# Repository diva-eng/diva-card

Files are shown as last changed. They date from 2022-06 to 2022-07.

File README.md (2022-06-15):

# Diva Card

Raspberry RP2040 based development board/card with builtin LED matrix

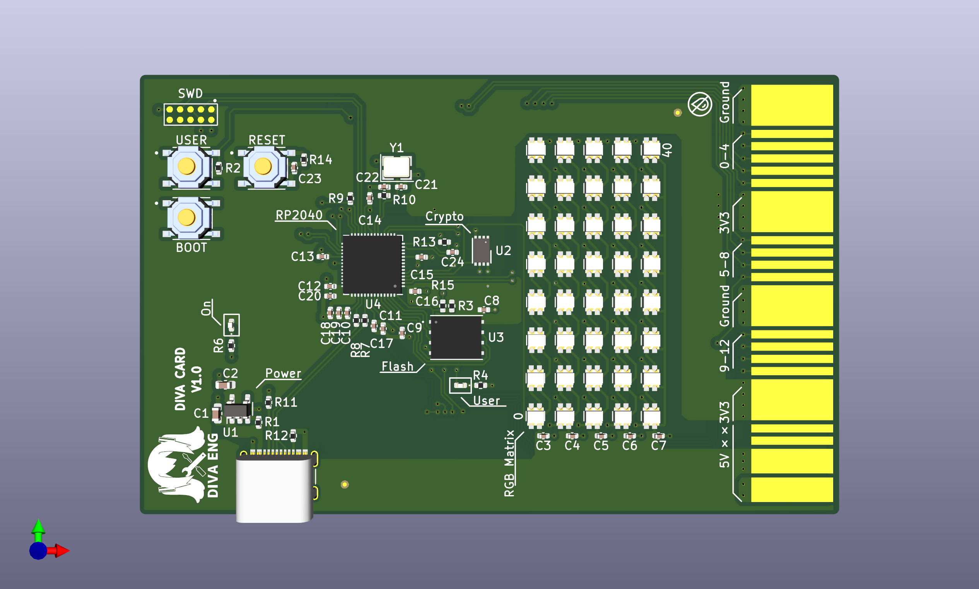
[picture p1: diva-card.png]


## Specs
* RP2040 Dual ARM Cortex-M0+ @ 133MHz
* Microchip ATECC608A crypto processor
* 8*5 WS2812C-2020 RGB LED matrix
* USB-C connector at USB 2.0 speed
* 1 user Button
* 1 user LED
* 13 user IO
* SWD tag connector
* Edge connector for IO/Power

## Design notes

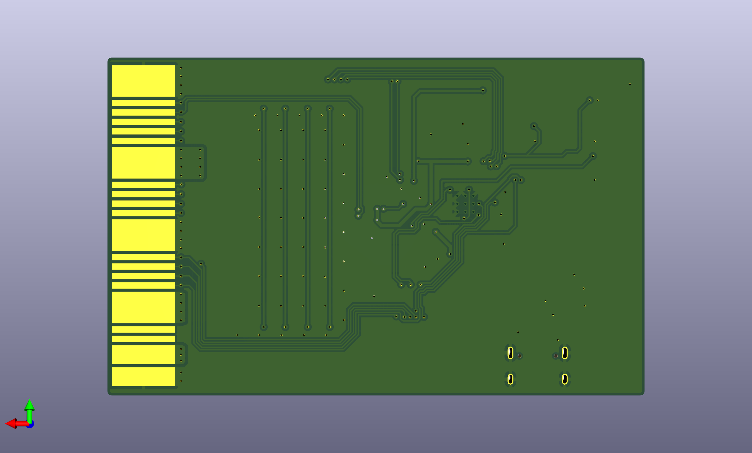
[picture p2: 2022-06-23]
diva-card-back.png

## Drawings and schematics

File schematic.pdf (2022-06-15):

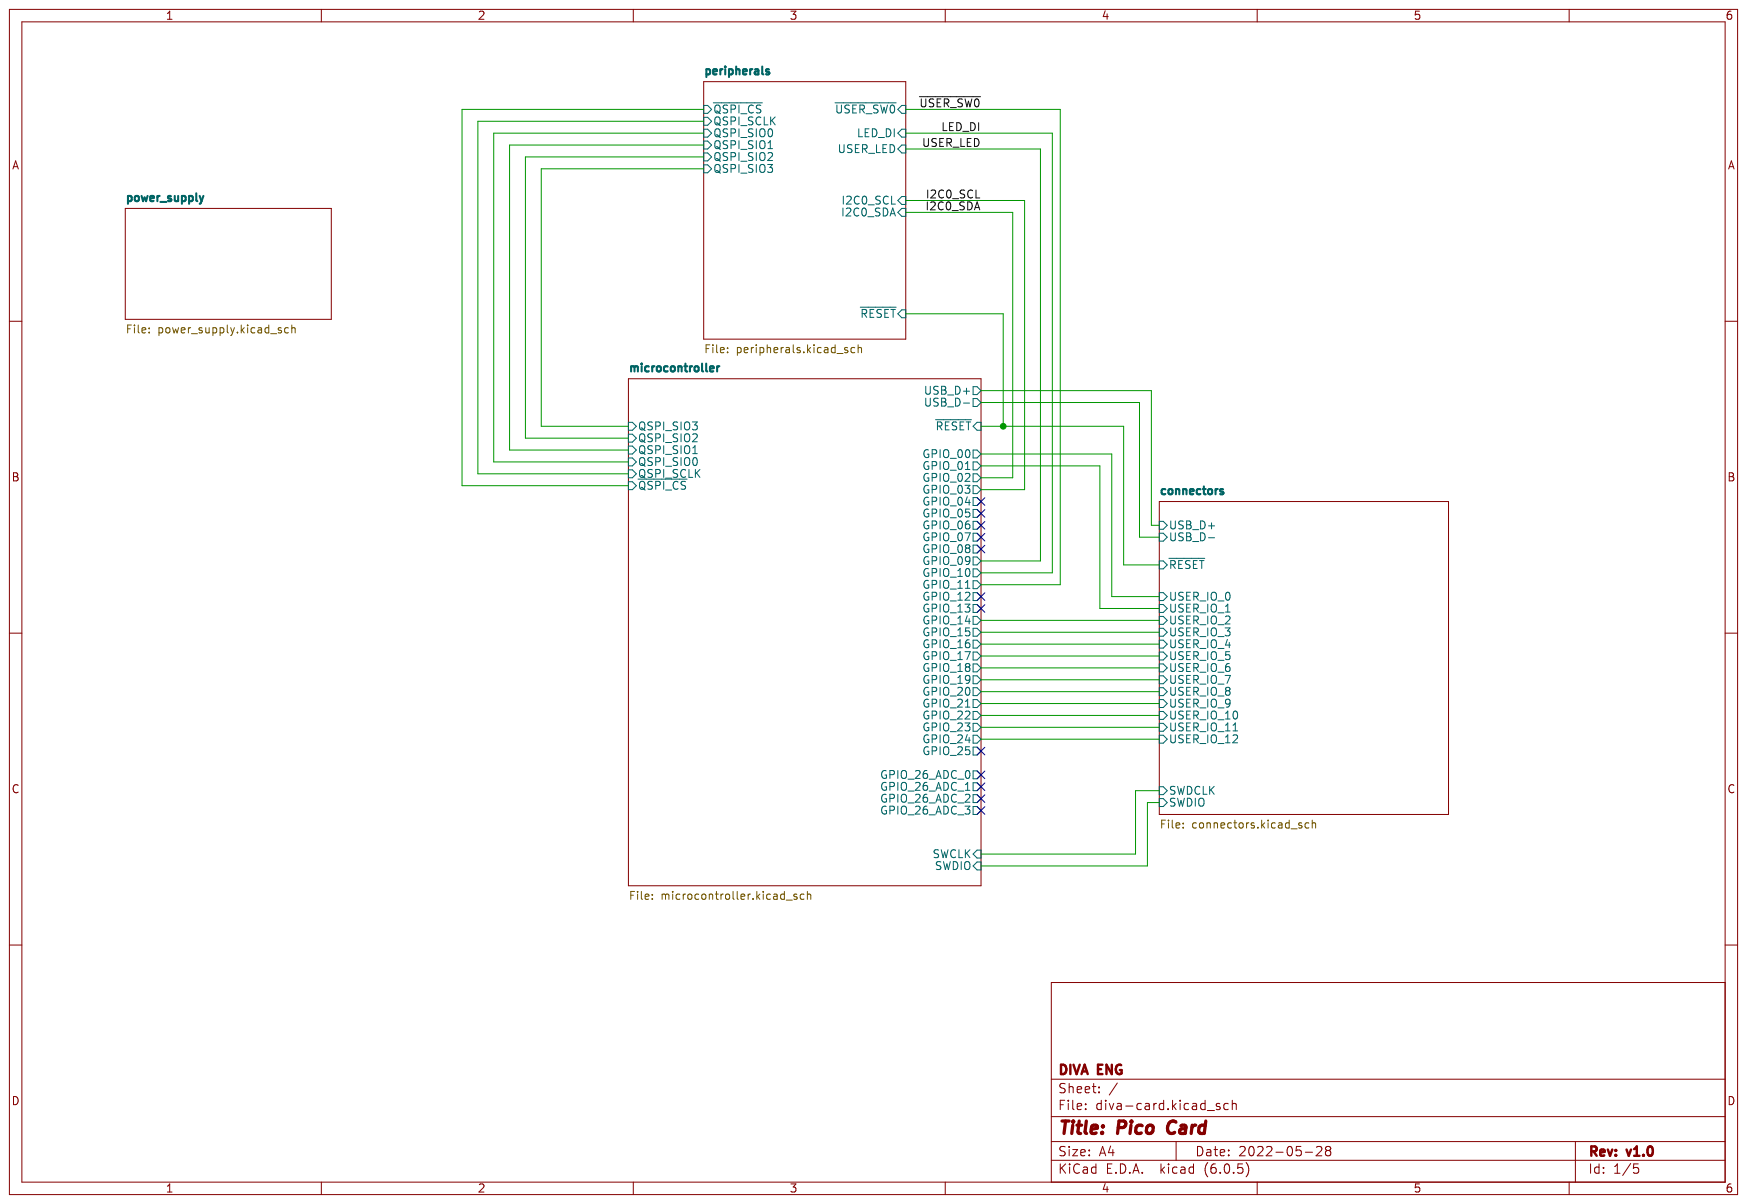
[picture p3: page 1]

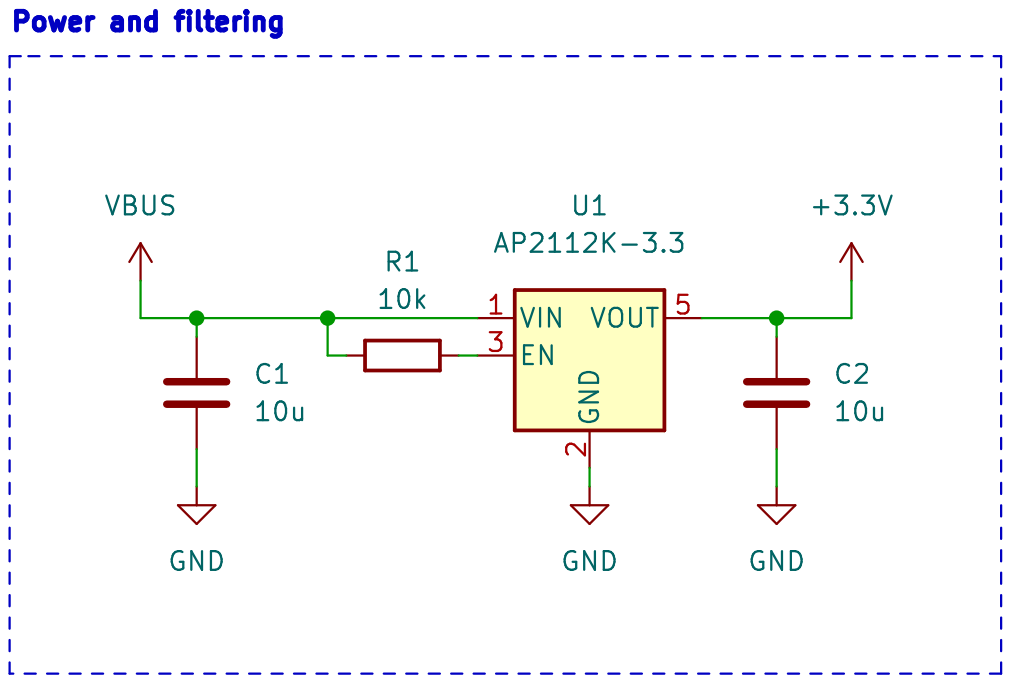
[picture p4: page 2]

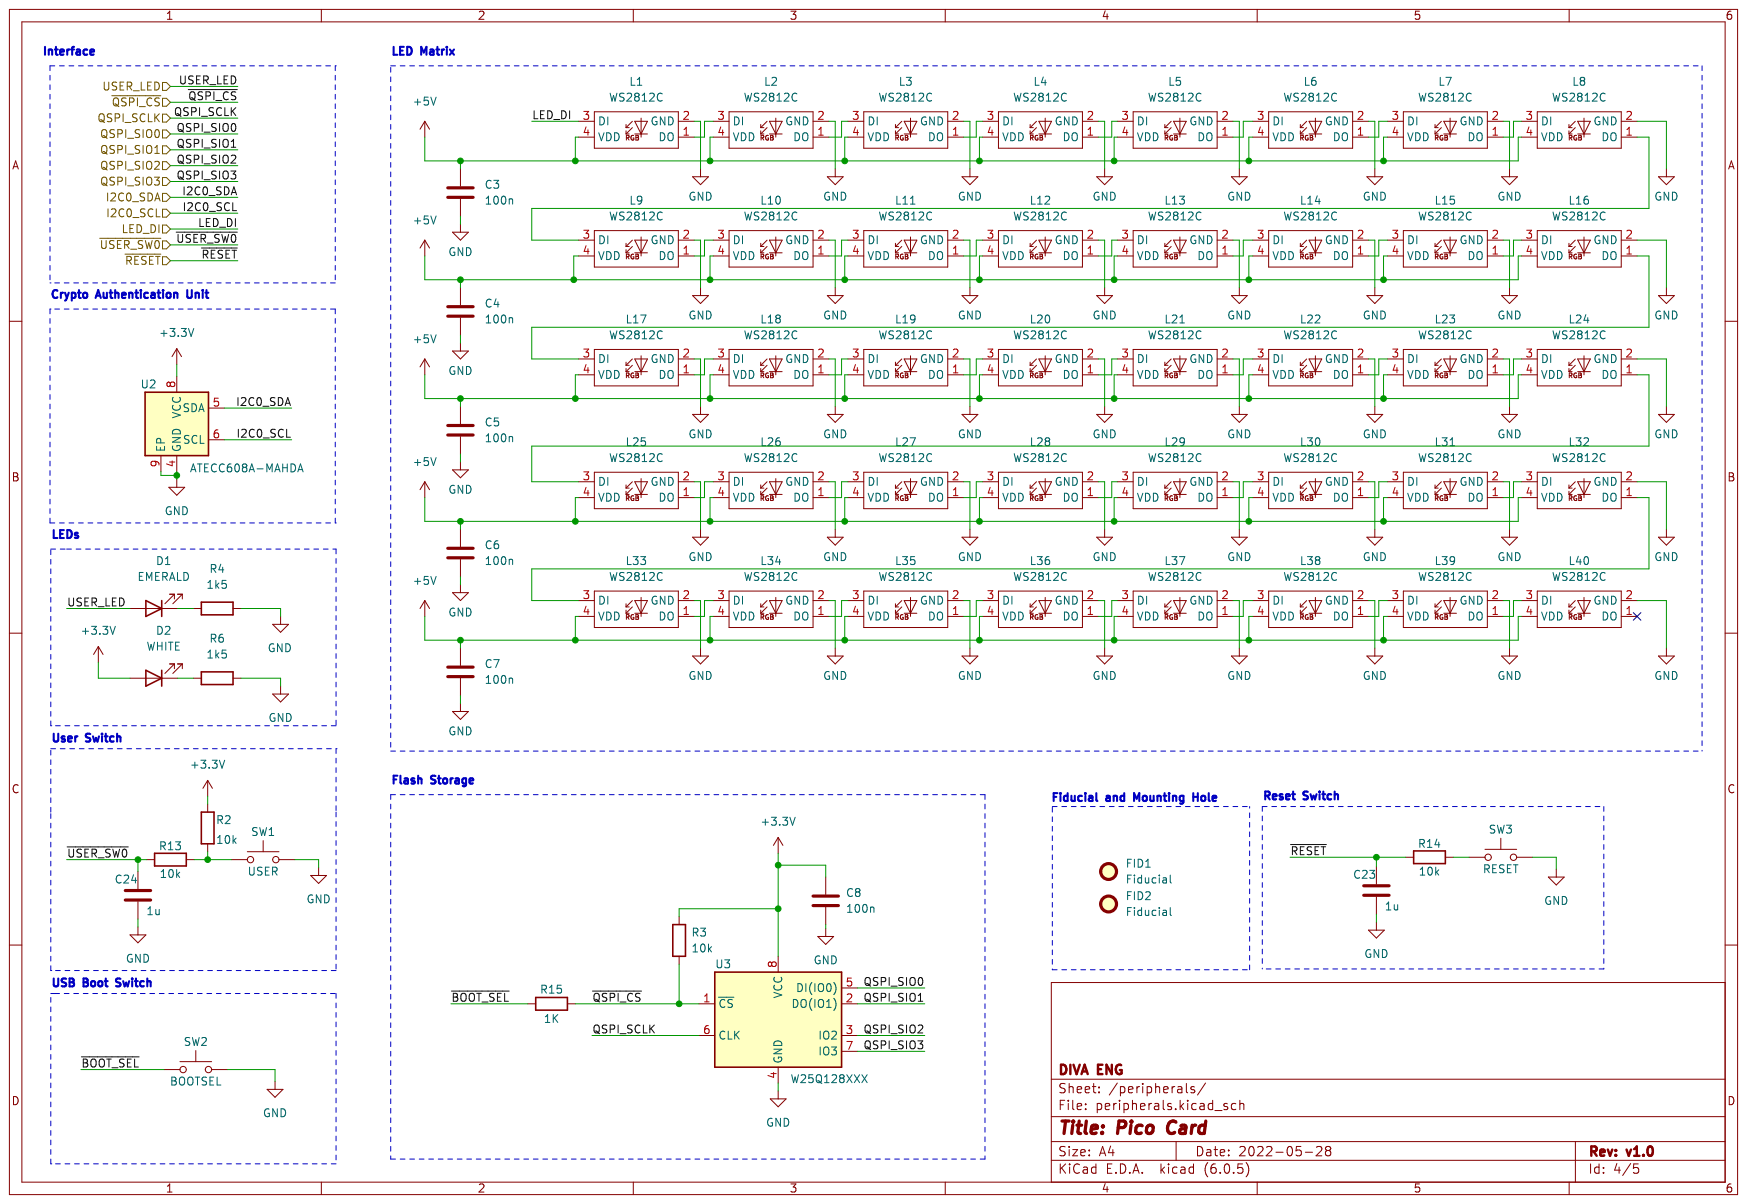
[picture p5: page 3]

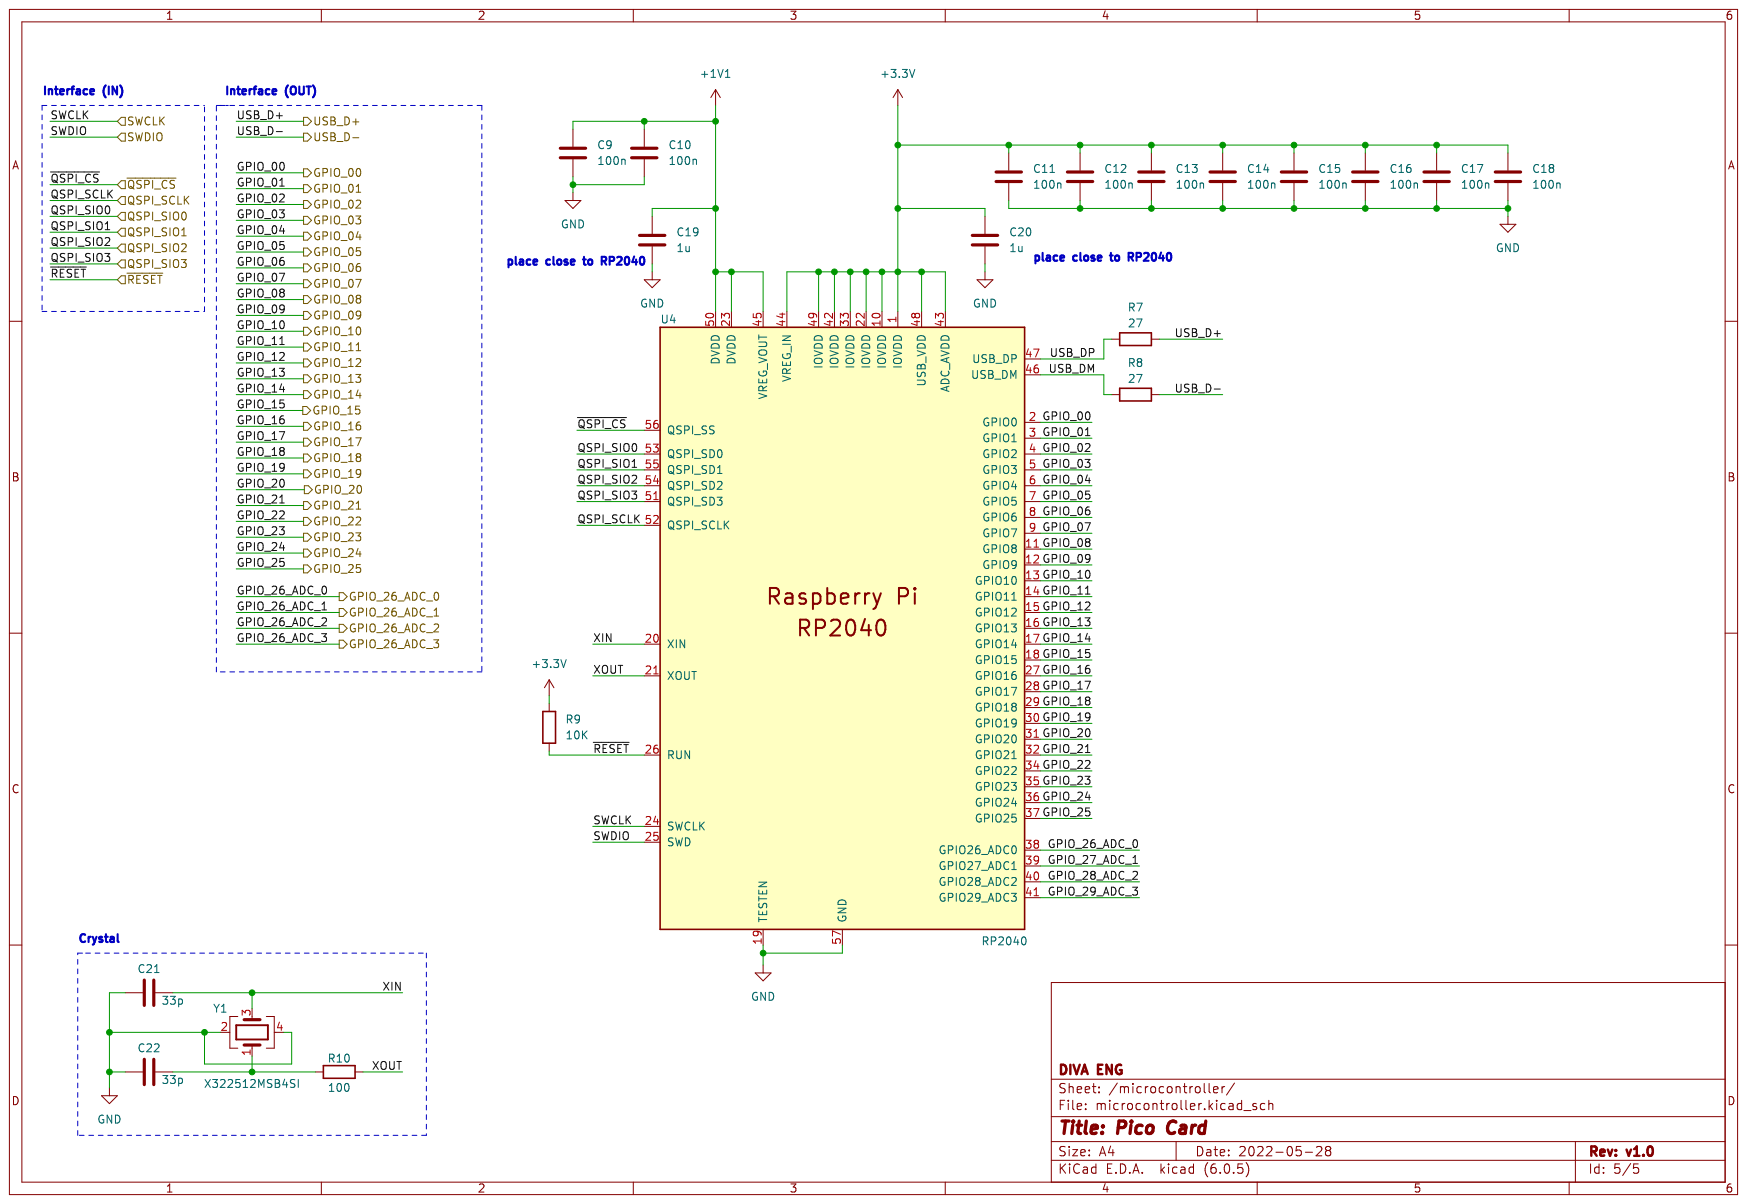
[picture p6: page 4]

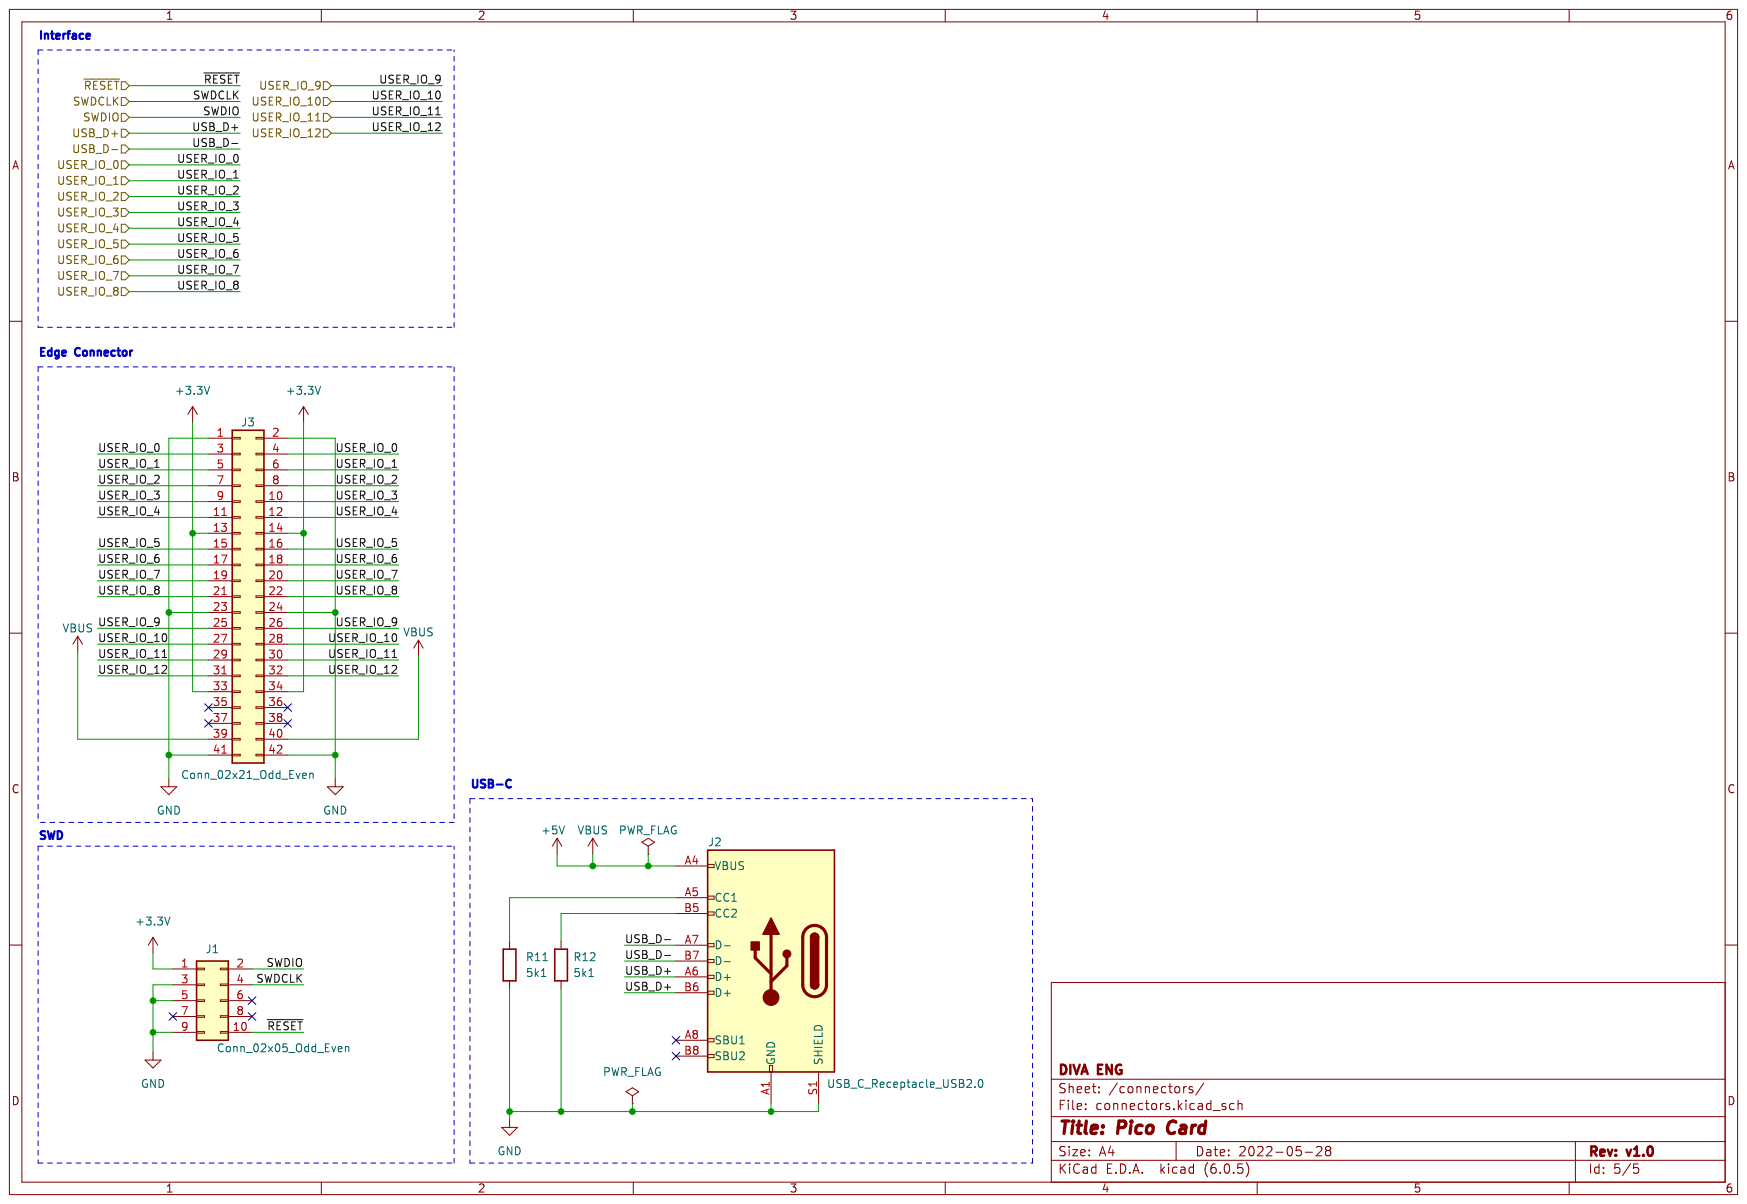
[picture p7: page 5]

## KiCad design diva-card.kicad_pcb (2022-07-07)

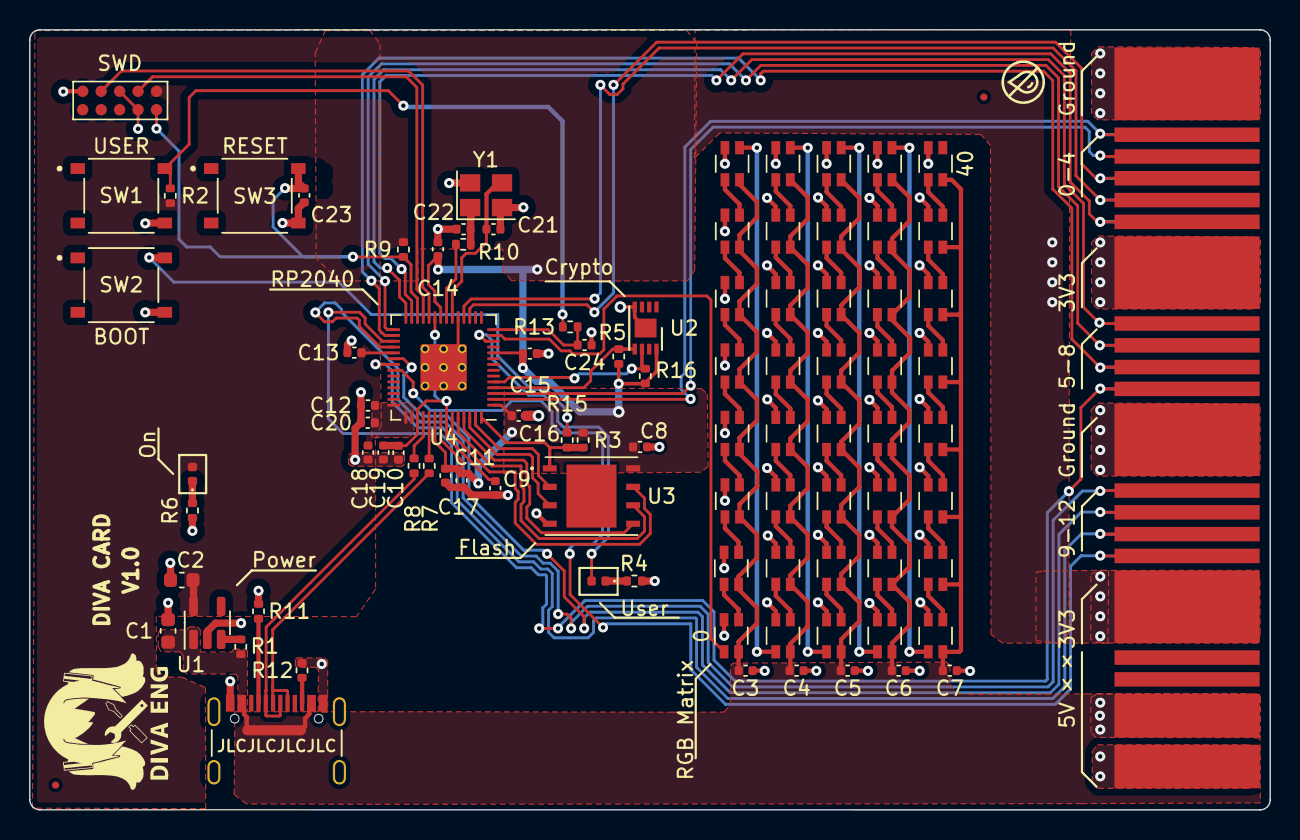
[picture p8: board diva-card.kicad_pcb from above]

Board: 2 copper layers, 85.4 x 53.7 mm, 94 parts (0 on the bottom side), 84 nets.

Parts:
C1, C2: 10u; C_0603_1608Metric
C3, C4, C5, C6, C7, C8, C9, C10, C11, C12, C13, C14, C15, C16, C17, C18: 100n; C_0402_1005Metric
C19, C20, C23, C24: 1u; C_0402_1005Metric
C21, C22: 33p; C_0402_1005Metric
D1: EMERALD; LED_0402_1005Metric
D2: WHITE; LED_0402_1005Metric
FID1, FID2: Fiducial; Fiducial_0.5mm_Mask1mm
J1: Conn_02x05_Odd_Even; Tag-Connect_TC2050-IDC-NL_2x05_P1.27mm_Vertical
J2: USB_C_Receptacle_USB2.0; USB_C_Receptacle_Palconn_UTC16-G
J3: Conn_02x21_Odd_Even; PICO_CARD_EDGE_21
L1, L2, L3, L4, L5, L6, L7, L8, L9, L10, L11, L12, L13, L14, L15, L16, L17, L18, L19, L20, L21, L22, L23, L24, L25, L26, L27, L28, L29, L30, L31, L32, L33, L34, L35, L36, L37, L38, L39, L40: WS2812C; WS2812C-2020
R1, R2, R3, R13: 10k; R_0402_1005Metric
R4, R6: 1k5; R_0402_1005Metric
R5, R16: 4.7k; R_0402_1005Metric
R7, R8: 27; R_0402_1005Metric
R9: 10K; R_0402_1005Metric
R10: 100; R_0402_1005Metric
R11, R12: 5k1; R_0402_1005Metric
R15: 1K; R_0402_1005Metric
SW1: USER; SW_TS-1187A-B-A-B
SW2: BOOTSEL; SW_TS-1187A-B-A-B
SW3: RESET; SW_TS-1187A-B-A-B
U1: AP2112K-3.3; SOT-23-5
U2: ATECC608A-MAHDA; DFN-8-1EP_3x2mm_P0.5mm_EP1.3x1.5mm
U3: W25Q128XXX; W25Q128JVPIQ TR
U4: RP2040; RP2040-QFN-56
Y1: X322512MSB4SI; Crystal_SMD_3225-4Pin_3.2x2.5mm

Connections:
+1V1: C9.1, C10.1, C19.1, U4.23 (DVDD), U4.45 (VREG_VOUT), U4.50 (DVDD)
+3V3: C2.1, C8.1, C11.1, C12.1, C13.1, C14.1, C15.1, C16.1, C17.1, C18.1, C20.1, D2.2 (A), J1.1, J3.13, J3.14, J3.33, J3.34, R2.1, R3.1, R5.1, R9.1, R16.1, U1.5 (VOUT), U2.8 (VCC), U3.8 (VCC), U4.1 (IOVDD), U4.10 (IOVDD), U4.22 (IOVDD), U4.33 (IOVDD), U4.42 (IOVDD), U4.43 (ADC_AVDD), U4.44 (VREG_IN), U4.48 (USB_VDD), U4.49 (IOVDD)
+5V: C1.1, C3.1, C4.1, C5.1, C6.1, C7.1, J2.A4 (VBUS), J2.A9 (VBUS), J2.B4 (VBUS), J2.B9 (VBUS), J3.39, J3.40, L1.4 (VDD), L2.4 (VDD), L3.4 (VDD), L4.4 (VDD), L5.4 (VDD), L6.4 (VDD), L7.4 (VDD), L8.4 (VDD), L9.4 (VDD), L10.4 (VDD), L11.4 (VDD), L12.4 (VDD), L13.4 (VDD), L14.4 (VDD), L15.4 (VDD), L16.4 (VDD), L17.4 (VDD), L18.4 (VDD), L19.4 (VDD), L20.4 (VDD), L21.4 (VDD), L22.4 (VDD), L23.4 (VDD), L24.4 (VDD), L25.4 (VDD), L26.4 (VDD), L27.4 (VDD), L28.4 (VDD), L29.4 (VDD), L30.4 (VDD), L31.4 (VDD), L32.4 (VDD), L33.4 (VDD), L34.4 (VDD), L35.4 (VDD), L36.4 (VDD), L37.4 (VDD), L38.4 (VDD), L39.4 (VDD), L40.4 (VDD), R1.1, U1.1 (VIN)
/I2C0_SCL: R16.2, U2.6 (SCL), U4.5 (GPIO3)
/I2C0_SDA: R5.2, U2.5 (SDA), U4.4 (GPIO2)
/LED_DI: L1.3 (DI), U4.13 (GPIO10)
/USER_LED: D1.2 (A), U4.12 (GPIO9)
/connectors/SWDCLK: J1.4, U4.24 (SWCLK)
/connectors/SWDIO: J1.2, U4.25 (SWD)
/connectors/USB_D+: J2.A6 (D+), J2.B6 (D+), R7.2
/connectors/USB_D-: J2.A7 (D-), J2.B7 (D-), R8.2
/connectors/USER_IO_0: J3.3, J3.4, U4.2 (GPIO0)
/connectors/USER_IO_1: J3.5, J3.6, U4.3 (GPIO1)
/connectors/USER_IO_2: J3.7, J3.8, U4.17 (GPIO14)
/connectors/USER_IO_3: J3.9, J3.10, U4.18 (GPIO15)
/connectors/USER_IO_4: J3.11, J3.12, U4.27 (GPIO16)
/connectors/USER_IO_5: J3.15, J3.16, U4.28 (GPIO17)
/connectors/USER_IO_6: J3.17, J3.18, U4.29 (GPIO18)
/connectors/USER_IO_7: J3.19, J3.20, U4.30 (GPIO19)
/connectors/USER_IO_8: J3.21, J3.22, U4.31 (GPIO20)
/connectors/USER_IO_9: J3.25, J3.26, U4.32 (GPIO21)
/connectors/USER_IO_10: J3.27, J3.28, U4.34 (GPIO22)
/connectors/USER_IO_11: J3.29, J3.30, U4.35 (GPIO23)
/connectors/USER_IO_12: J3.31, J3.32, U4.36 (GPIO24)
/connectors/~RESET: C23.1, J1.10, R9.2, SW3.1, U4.26 (RUN)
/microcontroller/QSPI_SCLK: U3.6 (CLK), U4.52 (QSPI_SCLK)
/microcontroller/QSPI_SIO0: U3.5 (DI(IO0)), U4.53 (QSPI_SD0)
/microcontroller/QSPI_SIO1: U3.2 (DO(IO1)), U4.55 (QSPI_SD1)
/microcontroller/QSPI_SIO2: U3.3 (IO2), U4.54 (QSPI_SD2)
/microcontroller/QSPI_SIO3: U3.7 (IO3), U4.51 (QSPI_SD3)
/microcontroller/USB_DM: R8.1, U4.46 (USB_DM)
/microcontroller/USB_DP: R7.1, U4.47 (USB_DP)
/microcontroller/XIN: C21.2, U4.20 (XIN), Y1.3
/microcontroller/XOUT: R10.2, U4.21 (XOUT)
/microcontroller/~QSPI_CS: R3.2, R15.2, U3.1 (~CS), U4.56 (QSPI_SS)
/peripherals/~BOOT_SEL: R15.1, SW2.1
/~USER_SW0: C24.1, R13.1, U4.14 (GPIO11)
GND: C1.2, C2.2, C3.2, C4.2, C5.2, C6.2, C7.2, C8.2, C9.2, C10.2, C11.2, C12.2, C13.2, C14.2, C15.2, C16.2, C17.2, C18.2, C19.2, C20.2, C21.1, C22.1, C23.2, C24.2, J1.3, J1.5, J1.9, J2.A1 (GND), J2.A12 (GND), J2.B1 (GND), J2.B12 (GND), J2.S1 (SHIELD), J3.1, J3.2, J3.23, J3.24, J3.41, J3.42, L1.2 (GND), L2.2 (GND), L3.2 (GND), L4.2 (GND), L5.2 (GND), L6.2 (GND), L7.2 (GND), L8.2 (GND), L9.2 (GND), L10.2 (GND), L11.2 (GND), L12.2 (GND), L13.2 (GND), L14.2 (GND), L15.2 (GND), L16.2 (GND), L17.2 (GND), L18.2 (GND), L19.2 (GND), L20.2 (GND), L21.2 (GND), L22.2 (GND), L23.2 (GND), L24.2 (GND), L25.2 (GND), L26.2 (GND), L27.2 (GND), L28.2 (GND), L29.2 (GND), L30.2 (GND), L31.2 (GND), L32.2 (GND), L33.2 (GND), L34.2 (GND), L35.2 (GND), L36.2 (GND), L37.2 (GND), L38.2 (GND), L39.2 (GND), L40.2 (GND), R4.2, R6.2, R11.2, R12.2, SW1.2, SW2.2, SW3.2, U1.2 (GND), U2.4 (GND), U2.9 (EP), U3.4 (GND), U4.19 (TESTEN), U4.57 (GND), Y1.2, Y1.4
unnamed: C22.2, R10.1, Y1.1
unnamed: D1.1 (K), R4.1
unnamed: D2.1 (K), R6.1
unnamed: J2.A5 (CC1), R11.1
unnamed: J2.B5 (CC2), R12.1
unnamed: L1.1 (DO), L2.3 (DI)
unnamed: L2.1 (DO), L3.3 (DI)
unnamed: L3.1 (DO), L4.3 (DI)
unnamed: L4.1 (DO), L5.3 (DI)
unnamed: L5.1 (DO), L6.3 (DI)
unnamed: L6.1 (DO), L7.3 (DI)
unnamed: L7.1 (DO), L8.3 (DI)
unnamed: L8.1 (DO), L9.3 (DI)
unnamed: L10.1 (DO), L11.3 (DI)
unnamed: L9.1 (DO), L10.3 (DI)
unnamed: L11.1 (DO), L12.3 (DI)
unnamed: L12.1 (DO), L13.3 (DI)
unnamed: L13.1 (DO), L14.3 (DI)
unnamed: L14.1 (DO), L15.3 (DI)
unnamed: L15.1 (DO), L16.3 (DI)
unnamed: L16.1 (DO), L17.3 (DI)
unnamed: L17.1 (DO), L18.3 (DI)
unnamed: L18.1 (DO), L19.3 (DI)
unnamed: L19.1 (DO), L20.3 (DI)
unnamed: L20.1 (DO), L21.3 (DI)
unnamed: L21.1 (DO), L22.3 (DI)
unnamed: L22.1 (DO), L23.3 (DI)
unnamed: L23.1 (DO), L24.3 (DI)
unnamed: L24.1 (DO), L25.3 (DI)
unnamed: L25.1 (DO), L26.3 (DI)
unnamed: L26.1 (DO), L27.3 (DI)
unnamed: L27.1 (DO), L28.3 (DI)
unnamed: L28.1 (DO), L29.3 (DI)
unnamed: L29.1 (DO), L30.3 (DI)
unnamed: L30.1 (DO), L31.3 (DI)
unnamed: L31.1 (DO), L32.3 (DI)
unnamed: L32.1 (DO), L33.3 (DI)
unnamed: L33.1 (DO), L34.3 (DI)
unnamed: L34.1 (DO), L35.3 (DI)
unnamed: L35.1 (DO), L36.3 (DI)
unnamed: L36.1 (DO), L37.3 (DI)
unnamed: L37.1 (DO), L38.3 (DI)
unnamed: L38.1 (DO), L39.3 (DI)
unnamed: L39.1 (DO), L40.3 (DI)
unnamed: R1.2, U1.3 (EN)
unnamed: R2.2, R13.2, SW1.1

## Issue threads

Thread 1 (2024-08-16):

Choice of 100 ohm resistor for crystal oscillator

DLehenbauer, 2024-08-16:
I was wondering how you chose the value of 100 ohms for the resistor (R10)?

I am working on a design using the same parts (RP2040 and X322512MSB4SI oscillator).  However, I kept the 1K resistor from the reference design.

My prototype works but requires a firmware workaround to increase the startup delay to 16ms or more.
```cmake
# On tested sample, 8ms was intermittent and 16ms was reliable.
# 64ms provides a large tolerance.
add_compile_definitions(PICO_XOSC_STARTUP_DELAY_MULTIPLIER=64)
```
I thought maybe you ran into the same issue and reduced the value of R10 to compensate?

r1cebank, 2024-09-08:
The reference design was using a different capacitor I recall and since we chose a different oscillator the feed resistor has also been adjusted to that oscillator. I do not recall what was the actual calculation done but it was based on the oscillator ESR https://www.lcsc.com/datasheet/lcsc_datasheet_2403291504_YXC-Crystal-Oscillators-X322512MSB4SI_C9002.pdf and existing designs using the same part. Hope this helps

DLehenbauer, 2024-09-09:
I appreciate the response.  Sounds like you got it right on the first try.  Thanks!

Closed 2024-09-09.

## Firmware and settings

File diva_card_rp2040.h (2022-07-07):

// -----------------------------------------------------
// NOTE: THIS HEADER IS ALSO INCLUDED BY ASSEMBLER SO
//       SHOULD ONLY CONSIST OF PREPROCESSOR DIRECTIVES
// -----------------------------------------------------

#ifndef _BOARDS_DIVA_CARD_RP2040_H
#define _BOARDS_DIVA_CARD_RP2040_H

// For board detection
#define DIVA_CARD_RP2040

// On some samples, the xosc can take longer to stabilize than is usual
#ifndef PICO_XOSC_STARTUP_DELAY_MULTIPLIER
#define PICO_XOSC_STARTUP_DELAY_MULTIPLIER 64
#endif

// --- UART ---
#ifndef PICO_DEFAULT_UART
#define PICO_DEFAULT_UART 0
#endif
#ifndef PICO_DEFAULT_UART_TX_PIN
#define PICO_DEFAULT_UART_TX_PIN 0
#endif
#ifndef PICO_DEFAULT_UART_RX_PIN
#define PICO_DEFAULT_UART_RX_PIN 1
#endif

//------------- LED -------------//
#ifndef PICO_DEFAULT_LED_PIN
#define PICO_DEFAULT_LED_PIN 9
#endif

#ifndef PICO_DEFAULT_WS2812_PIN
#define PICO_DEFAULT_WS2812_PIN 10
#endif

// --- I2C ---
#ifndef PICO_DEFAULT_I2C
#define PICO_DEFAULT_I2C 0
#endif
#ifndef PICO_DEFAULT_I2C_SDA_PIN
#define PICO_DEFAULT_I2C_SDA_PIN 4
#endif
#ifndef PICO_DEFAULT_I2C_SCL_PIN
#define PICO_DEFAULT_I2C_SCL_PIN 5
#endif

// --- SPI ---
#ifndef PICO_DEFAULT_SPI
#define PICO_DEFAULT_SPI 0
#endif
#ifndef PICO_DEFAULT_SPI_SCK_PIN
#define PICO_DEFAULT_SPI_SCK_PIN 18
#endif
#ifndef PICO_DEFAULT_SPI_TX_PIN
#define PICO_DEFAULT_SPI_TX_PIN 19
#endif
#ifndef PICO_DEFAULT_SPI_RX_PIN
#define PICO_DEFAULT_SPI_RX_PIN 16
#endif
#ifndef PICO_DEFAULT_SPI_CSN_PIN
#define PICO_DEFAULT_SPI_CSN_PIN 17
#endif

//------------- FLASH -------------//

// Use slower generic flash access
#define PICO_BOOT_STAGE2_CHOOSE_W25Q080 1

#ifndef PICO_FLASH_SPI_CLKDIV
#define PICO_FLASH_SPI_CLKDIV 2
#endif

#ifndef PICO_FLASH_SIZE_BYTES
#define PICO_FLASH_SIZE_BYTES (16 * 1024 * 1024)
#endif

// All boards have B1 RP2040
#ifndef PICO_RP2040_B0_SUPPORTED
#define PICO_RP2040_B0_SUPPORTED 0
#endif

#endif

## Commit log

2022-05-31 Init commit, schematic design, footprints
    [connectors.kicad_sch, microcontroller.kicad_sch, peripherals.kicad_sch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]
2022-06-01 All component except led matrix
    [connectors.kicad_sch, microcontroller.kicad_sch, peripherals.kicad_sch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]
2022-06-01 finish schematic, prep pcb
    [connectors.kicad_sch, microcontroller.kicad_sch, peripherals.kicad_sch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]
2022-06-05 Basic routing MCU, crystal, flash, crypto
    [connectors.kicad_sch, microcontroller.kicad_sch, pico-card.kicad_pcb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]
2022-06-07 Basic routing complete, rename
    [connectors.kicad_sch, diva-card.kicad_pcb, diva-card.kicad_sch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]
2022-06-07 Adding test gerber and bom
    [diva-card-CuBottom.gbr, diva-card-CuTop.gbr, diva-card-EdgeCuts.gbr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]
2022-06-08 updating footprints to udfn
    [connectors.kicad_sch, diva-card.kicad_pcb, diva-card.kicad_sch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]
2022-06-11 Adding schematic pdf
    [connectors.kicad_sch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]
2022-06-12 schematic update
    [connectors.kicad_sch, microcontroller.kicad_sch]
2022-06-13 design flaw fix
    [connectors.kicad_sch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]
2022-06-13 update schematic and photo
2022-06-13 Remove trace under usb trace
    [diva-card.kicad_pcb, diva-card.kicad_sch, microcontroller.kicad_sch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]
2022-06-15 update power delivery
    [diva-card-CuBottom.gbr, diva-card-CuTop.gbr, diva-card-EdgeCuts.gbr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]
2022-06-15 update schematic
    [diva-card.kicad_pcb]
2022-06-23 Production Design V1.0
    [connectors.kicad_sch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]
2022-07-07 Fix issues found on production prototype
    [diva-card.kicad_pcb, diva-card.kicad_sch, peripherals.kicad_sch]
2022-07-07 adding board config
